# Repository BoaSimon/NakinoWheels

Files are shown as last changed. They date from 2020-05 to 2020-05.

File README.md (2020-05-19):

# NakinoWheels
An open-source camera control hand-wheels project based on the Kino Wheels project at https://www.kinowheels.com/

I'm just dumping all the files up here right away, but when I've got some time after work today I'll reorganize and make things clear.

STL Files:
The case to print!

NaKinoWheels_UE4.ino
Arduino Sketch which communicates with UE4 over Serial. Requires the UE4Duino2 plugin for Unreal Engine: https://forums.unrealengine.com/community/community-content-tools-and-tutorials/121573-free-windows-only-ue4duino-2-arduino-com-port-communication

NaKinoWheels_KinoSimulator.ino
Arduino Sketch which communicates with the original Kino Wheels Simulator, at https://www.kinowheels.com/simulator/

NaKinoWheels_PPM.ino
Arduino Sketch which outputs PPM from a 3.5mm jack. Good for feeding the Trainer port on any RC Transmitter to send signal to MoVI/Ronin via an S-Bus receiver. I've got a plan to make a simple module that will take the PPM signal and transmit directly through a JR Module to an S-Bus Receiver, but I'll do that when I've got an actual physical production job coming up...

NaKinoController.uasset
The UE4 blueprint for reading Serial signal from the NaKino wheels! It only ticks during runtime, so you won't see anything until you launch PIE.

-- PARTS LIST --

McMaster Carr:

2x Black Aluminum Unthreaded Through-Hole Spoked Hand Wheel, Dished Wheel with Revolving Handle, 6" Diameter, 1/2" Hole
https://www.mcmaster.com/60265K25-60265K25

2x Tapped D-Profile Rotary Shaft, 1045 Carbon Steel, 1/2" Diameter, 6" Long
https://www.mcmaster.com/8017T3-8017T3

2x 	Low-Profile Mounted Sealed Steel Ball Bearing for 1/2" Shaft Diameter
https://www.mcmaster.com/5913K61-5913K61

1x 	Tapered Heat-Set Inserts for Plastic, 8-32 Thread Size, 0.185" Installed Length, Brass, Packs of 100
https://www.mcmaster.com/93365A140-93365A140

1x Zinc-Plated Alloy Steel Hex Drive Flat Head Screw, 8-32 Thread Size, 1/2" Long, Packs of 25
https://www.mcmaster.com/91263A524-91263A524

1x Tapered Heat-Set Inserts for Plastic, 1/4"-20 Thread Size, 0.3" Installed Length, Brass
https://www.mcmaster.com/93365A160-93365A160

1x Tapered Heat-Set Inserts for Plastic, 3/8"-16 Thread Size, 3/8" Installed Length, Brass
https://www.mcmaster.com/93365A290-93365A290

Amazon:

2x 600P/R Rotary Encoder, Aideepen AB 2 Phase Incremental Rotary Encoder 6mm Shaft 5V-24V Wide Voltage
https://www.amazon.com/gp/product/B01MZ4V1XP/ref=ppx_yo_dt_b_asin_title_o00_s00?ie=UTF8&psc=1

1x E-Projects 100EP51210K0 10k Ohm Resistors, 1/2 W, 5% (Pack of 100)
https://www.amazon.com/gp/product/B0185FIOTA/ref=ppx_yo_dt_b_asin_title_o01_s00?ie=UTF8&psc=1

1x ELEGOO MEGA 2560 R3 Board ATmega2560 ATMEGA16U2 + USB Cable Compatible with Arduino IDE, RoHS Compliant
https://www.amazon.com/gp/product/B01H4ZLZLQ/ref=ppx_yo_dt_b_asin_title_o01_s00?ie=UTF8&psc=1

1x Onyehn TRRS 3.5mm Audio Jack Breakout MP3 Stereo Headphone Video Jack Module for Arduino (Pack of 5pcs)
https://www.amazon.com/gp/product/B07L3P93ZD/ref=ppx_yo_dt_b_asin_title_o01_s00?ie=UTF8&psc=1

1x EDGELEC 120pcs Breadboard Jumper Wires 10cm 15cm 20cm 30cm 40cm 50cm 100cm Optional Dupont Wire Assorted Kit Male to Female Male to Male Female to Female Multicolored Ribbon Cable
https://www.amazon.com/gp/product/B07GD1XFWV/ref=ppx_yo_dt_b_asin_title_o01_s01?ie=UTF8&th=1

1x Hornet Tire - 1/4oz Grey Lead Free Adhesive Backed Wheel Weights (48pcs)
https://www.amazon.com/gp/product/B00ZMD8SDG/ref=ppx_yo_dt_b_asin_title_o01_s01?ie=UTF8&psc=1

1x TWTADE / 3pcs wh138 100 ohm Potentiometer Single Turn Rotary Linear Variable Potentiometer +3pcs Black Aluminum Alloy knob
https://www.amazon.com/gp/product/B07DHGHQPQ/ref=ppx_yo_dt_b_search_asin_title?ie=UTF8&psc=1

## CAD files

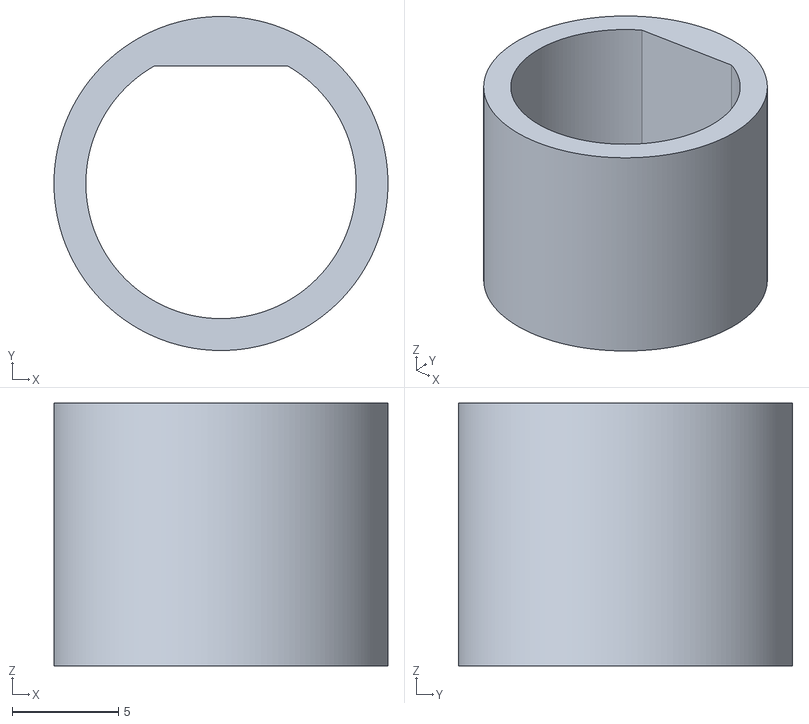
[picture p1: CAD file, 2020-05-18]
NakinoShaftSleeve.stl
15.7 x 15.7 x 12.3

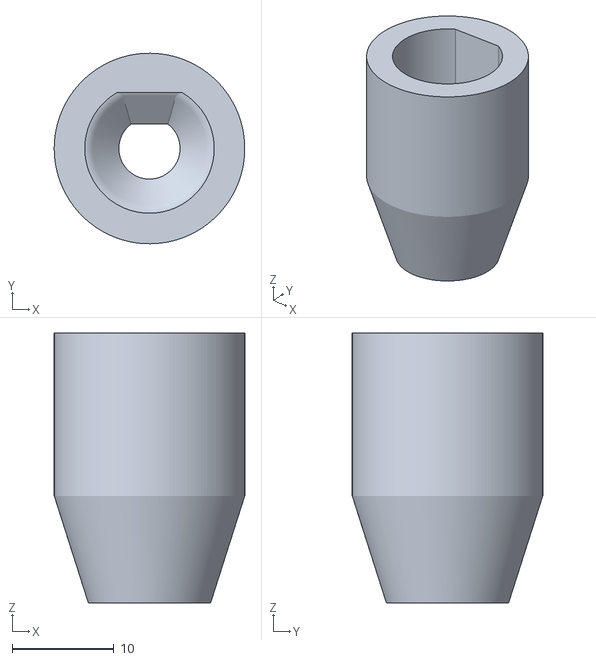
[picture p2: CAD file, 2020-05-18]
NakinoCoupler.stl
18.7 x 18.7 x 26.5

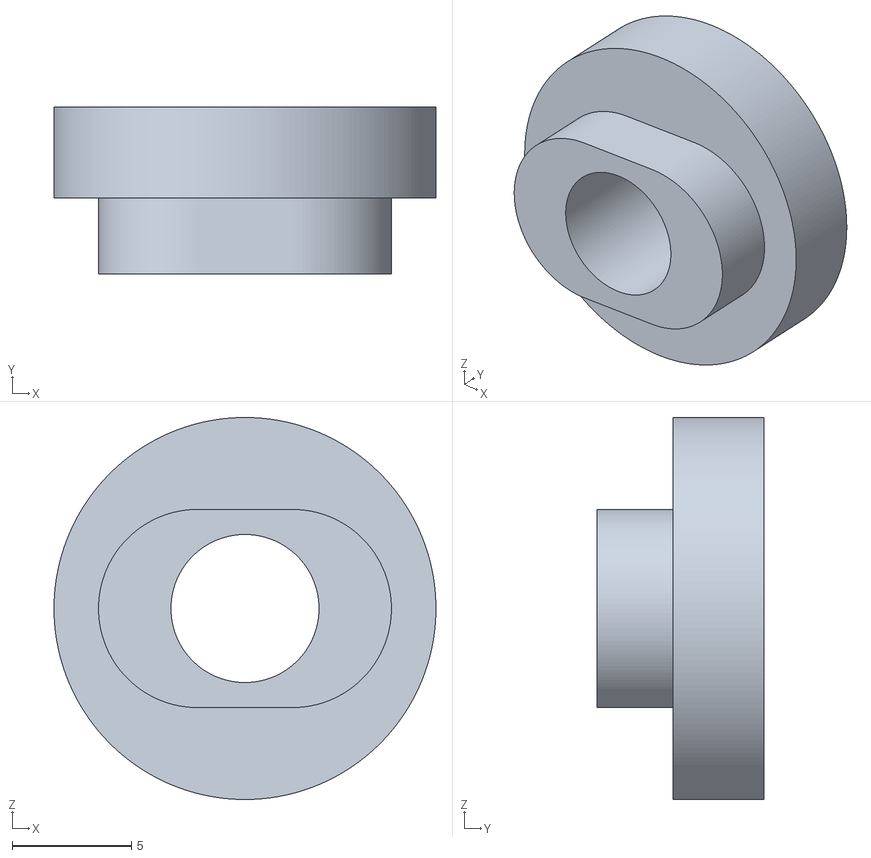
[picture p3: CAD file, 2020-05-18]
NakinoMountNut.stl
16.0 x 7.00 x 16.0

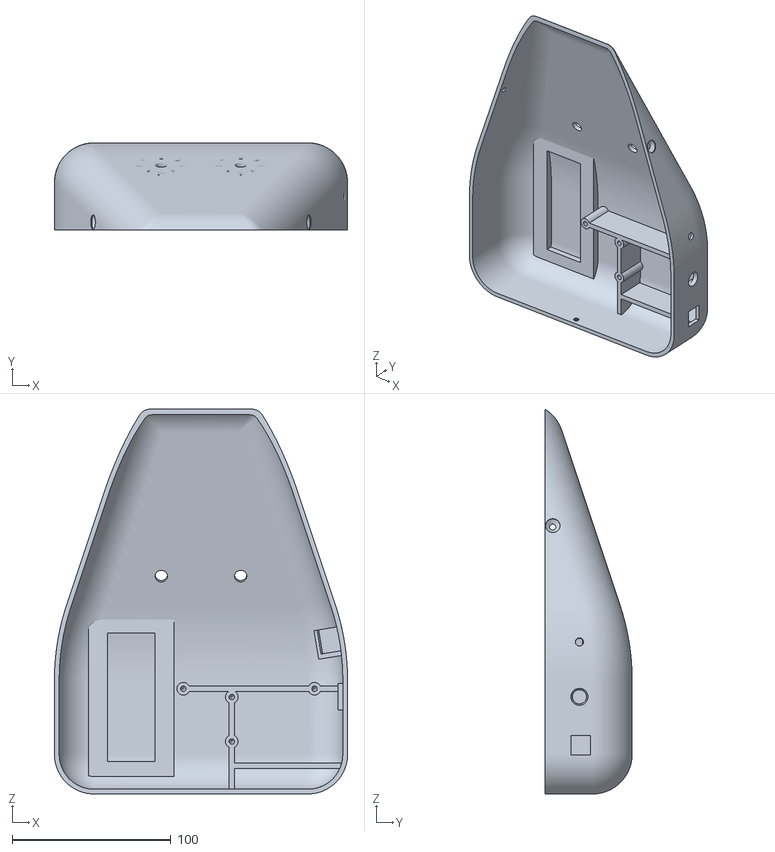
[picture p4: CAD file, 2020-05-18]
NaKinoLid.stl
184.6 x 55.0 x 242.4

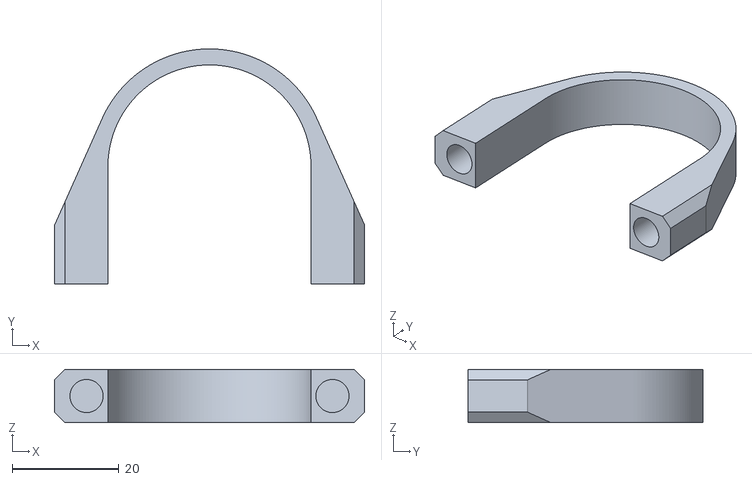
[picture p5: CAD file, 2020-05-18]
NaKinoEncoderStrap.stl
58.0 x 44.0 x 10.0

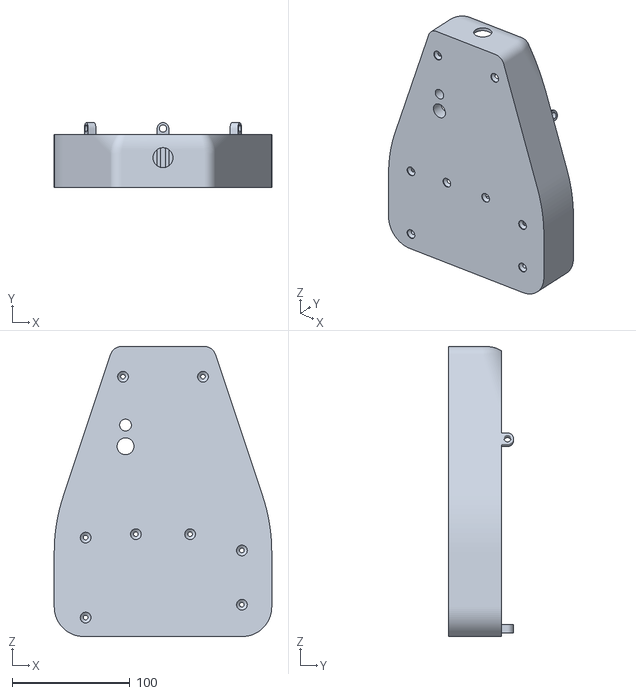
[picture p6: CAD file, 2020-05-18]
NaKinoBase.stl
184.6 x 55.0 x 246.1

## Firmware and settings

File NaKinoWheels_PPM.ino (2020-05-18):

#include <MD_REncoder.h>

// ----- VARIABLES -----
// PPM Variables
unsigned int ppm[16]; // the array of values for the timer1 interrupt timings
int curPpm = 0; // the position in the array of timings
byte curPpmMax; // the actual number of timer steps
byte loopCount = 0; // a crude substitute for delay()

//Rotary Encoder Variables
float pulsesX=305, XA_SIG=0, XB_SIG=1, pulsesY=305, YA_SIG=0, YB_SIG=1, xSpd=0, ySpd=0, xpotTest, ypotTest;

//Adjust these variables as needed
char pulsePin = 9; // the digital pin for sending PPM pulses to the transmitter
int xPotPin = 1;
int yPotPin = 0;
float xPotRaw = 0;
float yPotRaw = 0;
float SpdMult = 0.05;

//Smoothing Variables
const int numReadings = 6;

float pReadings[numReadings];      // the readings from the analog input
int pReadIndex = 0;              // the index of the current reading
float pTotal = 1830;                  // the running total
float pAverage = 305;                // the average
float tReadings[numReadings];      // the readings from the analog input
int tReadIndex = 0;              // the index of the current reading
float tTotal = 1830;                  // the running total
float tAverage = 305;                // the average


// ----- SETUP -----
void setup(){
//Rotary Encoder Setup
attachInterrupt(0, XA_RISE, RISING); // Pin 2
attachInterrupt(1, XB_RISE, RISING); // Pin 3
attachInterrupt(4, YA_RISE, RISING); // Pin 19
attachInterrupt(5, YB_RISE, RISING); // Pin 18

// Serial Output Setup
Serial.begin(115200);
delay(100);
Serial.print("Connected");


// PPM Setup
//set the pin directions
pinMode(pulsePin, OUTPUT);
// set the timing values
  ppm[0] = 1475; //3775; // long pulse - see notes above
  ppm[1] = 75; // short dividing pulse
  ppm[2] = 305; // loco1 ch1
  ppm[3] = 75; // short
  ppm[4] = 305; // loco2 ch2
  ppm[5] = 75; // short
  ppm[6] = 305; // loco3 ch3
  ppm[7] = 75; // short
  ppm[8] = 305; // loco4 ch4
  ppm[9] = 75; // short
  ppm[10] = 305; // loco5 ch5
  ppm[11] = 75; // short
  ppm[12] = 305; // loco6 ch6
  ppm[13] = 75; // short
  ppm[14] = 400; // loco7 ch7
  ppm[15] = 75; // short

  curPpmMax = 16; // the number of timer values
  curPpm = 0; // the starting position in the array of timings
  
  // setup and start timer interrupts
  // ppm is achieved by sending different delays to the timer interrupt
  noInterrupts();
    TCCR1A = 0;     // set entire TCCR1A register to 0
    TCCR1B = 0;     // same for TCCR1B
    // set compare match register to desired timer count:
    OCR1A = 1000; // It works by causing an interrupt when TCNT2 counts up to this number
                  // This number will be set from the ppm array when the program is running
    digitalWrite(pulsePin,0); // start with pin low
    // turn on CTC mode: Clear Timer on Compare
    bitSet(TCCR1B, WGM12);
    // Set CS10 and CS11 bits for 64 prescaler: 10, 12 = 1024
    bitSet(TCCR1B, CS10);
    bitSet(TCCR1B, CS11);
    bitClear(TCCR1B, CS12);
    // enable timer compare A interrupt:
    bitSet(TIMSK1, OCIE1A);
  interrupts();


   for (int thisReading = 0; thisReading < numReadings; thisReading++) {
    pReadings[thisReading] = 305;
   }
   for (int thisReading = 0; thisReading < numReadings; thisReading++) {
    tReadings[thisReading] = 305;
  }
  
}

// ----- ROTARY ENCODER SETUP -----

//X-Axis
void XA_RISE(){
detachInterrupt(0);
//delay(1);
XA_SIG=1;

if(XB_SIG==0)
pulsesX = pulsesX + xSpd;//moving forward
pulsesX = constrain(pulsesX, 100, 500);
if(XB_SIG==1)
pulsesX = pulsesX - xSpd;//moving reverse
pulsesX = constrain(pulsesX, 100, 500);

attachInterrupt(0, XA_FALL, FALLING);
}

void XA_FALL(){
detachInterrupt(0);
//delay(1);
XA_SIG=0;

if(XB_SIG==1)
pulsesX = pulsesX + xSpd;//moving forward
pulsesX = constrain(pulsesX, 100, 500);
if(XB_SIG==0)
pulsesX = pulsesX - xSpd;//moving reverse
pulsesX = constrain(pulsesX, 100, 500);

attachInterrupt(0, XA_RISE, RISING);
}

void XB_RISE(){
detachInterrupt(1);
//delay(1);
XB_SIG=1;

if(XA_SIG==1)
pulsesX = pulsesX + xSpd;//moving forward
pulsesX = constrain(pulsesX, 100, 500);
if(XA_SIG==0)
pulsesX = pulsesX - xSpd;//moving reverse
pulsesX = constrain(pulsesX, 100, 500);

attachInterrupt(1, XB_FALL, FALLING);
}

void XB_FALL(){
detachInterrupt(1);
//delay(1);
XB_SIG=0;

if(XA_SIG==0)
pulsesX = pulsesX + xSpd;//moving forward
 pulsesX = constrain(pulsesX, 100, 500);
if(XA_SIG==1)
pulsesX = pulsesX - xSpd;//moving reverse
pulsesX = constrain(pulsesX, 100, 500);

attachInterrupt(1, XB_RISE, RISING);
}

//Y-Axis
void YA_RISE(){
detachInterrupt(4);
//delay(1);
YA_SIG=1;

if(YB_SIG==0)
pulsesY = pulsesY + ySpd;//moving forward
 pulsesY = constrain(pulsesY, 100, 500);
if(YB_SIG==1)
pulsesY = pulsesY - ySpd;//moving reverse
 pulsesY = constrain(pulsesY, 100, 500);

attachInterrupt(4, YA_FALL, FALLING);
}

void YA_FALL(){
detachInterrupt(4);
//delay(1);
YA_SIG=0;

if(YB_SIG==1)
pulsesY = pulsesY + ySpd;//moving forward
 pulsesY = constrain(pulsesY, 100, 500);
if(YB_SIG==0)
pulsesY = pulsesY - ySpd;//moving reverse
 pulsesY = constrain(pulsesY, 100, 500);

attachInterrupt(4, YA_RISE, RISING);
}

void YB_RISE(){
detachInterrupt(5);
//delay(1);
YB_SIG=1;

if(YA_SIG==1)
pulsesY = pulsesY + ySpd;//moving forward
 pulsesY = constrain(pulsesY, 100, 500);
if(YA_SIG==0)
pulsesY = pulsesY - ySpd;//moving reverse
 pulsesY = constrain(pulsesY, 100, 500);

attachInterrupt(5, YB_FALL, FALLING);
}

void YB_FALL(){
detachInterrupt(5);
//delay(1);
YB_SIG=0;

if(YA_SIG==0)
pulsesY = pulsesY + ySpd;//moving forward
 pulsesY = constrain(pulsesY, 100, 500);
if(YA_SIG==1)
pulsesY = pulsesY - ySpd;//moving reverse
 pulsesY = constrain(pulsesY, 100, 500);

attachInterrupt(5, YB_RISE, RISING);
}



// ----- LOOP -----
void loop(){
xPotRaw = analogRead(xPotPin);
yPotRaw = analogRead(yPotPin);
xSpd = SpdMult * (xPotRaw / 1018);
ySpd = SpdMult * (yPotRaw / 1018);

if (loopCount == 1) {

  //Smoothing
// subtract the last reading:
pTotal = pTotal - pReadings[pReadIndex];
 // read from the sensor:
  pReadings[pReadIndex] = pulsesX;
  // add the reading to the total:
  pTotal = pTotal + pReadings[pReadIndex];
  // advance to the next position in the array:
  pReadIndex = pReadIndex + 1;

  // if we're at the end of the array...
  if (pReadIndex >= numReadings) {
    // ...wrap around to the beginning:
    pReadIndex = 0;
  }

  // calculate the average:
  pAverage = pTotal / numReadings;

 // subtract the last reading:
tTotal = tTotal - tReadings[tReadIndex];
 // read from the sensor:
  tReadings[tReadIndex] = pulsesY;
  // add the reading to the total:
  tTotal = tTotal + tReadings[tReadIndex];
  // advance to the next position in the array:
  tReadIndex = tReadIndex + 1;

  // if we're at the end of the array...
  if (tReadIndex >= numReadings) {
    // ...wrap around to the beginning:
    tReadIndex = 0;
  }

  // calculate the average:
  tAverage = tTotal / numReadings;
  
    // the reading must be converted from the range 0 - 1023 to the range 250 - 500
    //   which means dividing by 4 and adding 180 to give 305 at the centre
    //pulsesX = constrain(pulsesX, 250, 500);
    //pulsesY = constrain(pulsesY, 250, 500);
    
   
    //xpotTest = constrain(xPotRaw, 100, 500);
    //ypotTest = constrain(yPotRaw, 100, 500);
    ppm[4] = pAverage;       
    ppm[6] = tAverage;
    //Serial.print(pulsesX);
    Serial.println(pAverage);
  }

  loopCount = loopCount + 1; // it will roll over to zero automatically

/*Serial.print("p");
Serial.print(pulsesX);
Serial.print("t");
Serial.print(pulsesY);
Serial.println(",");
//Serial.print("panSpeed");
//Serial.print(xSpd);
//Serial.print("tiltSpeed");
//Serial.print(ySpd);
//Serial.println("end");
delay(60);
*/

}


// interrupt routine that is triggered when the timer counts up to the preset value
ISR(TIMER1_COMPA_vect) {
  noInterrupts();
    digitalWrite(pulsePin, !digitalRead(pulsePin)); // change the state of the pin
    OCR1A = ppm[curPpm]; // set the value for the next time interval
    curPpm = ((curPpm + 1) % curPpmMax); // move the index on
                                         // the modulus operator makes the index roll over to the start
  interrupts();
}
